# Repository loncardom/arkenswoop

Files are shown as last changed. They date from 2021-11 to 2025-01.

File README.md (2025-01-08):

# Arkenswoop

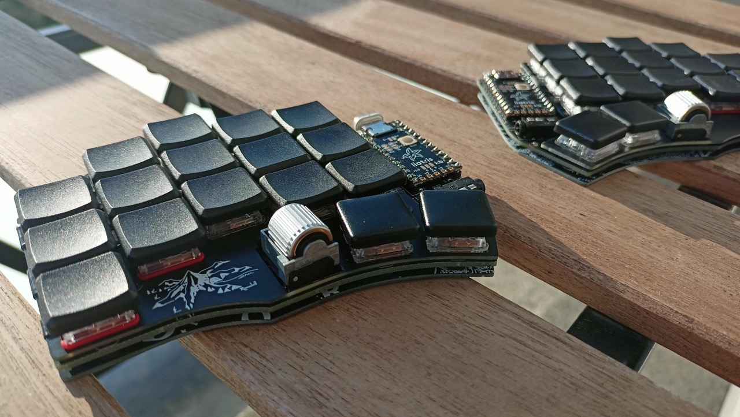
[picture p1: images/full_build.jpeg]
Fully assembled Arkenswoop


A WIP fork of [jimmerricks's Swoop](https://github.com/jimmerricks/swoop), which is a fork of [David Barr's Sweep](https://github.com/davidphilipbarr/Sweep), which is itself based on the fabulous [Ferris by Pierre Chevalier](https://github.com/pierrechevalier83/ferris).

| Front | Back |
| :---: | :---: |
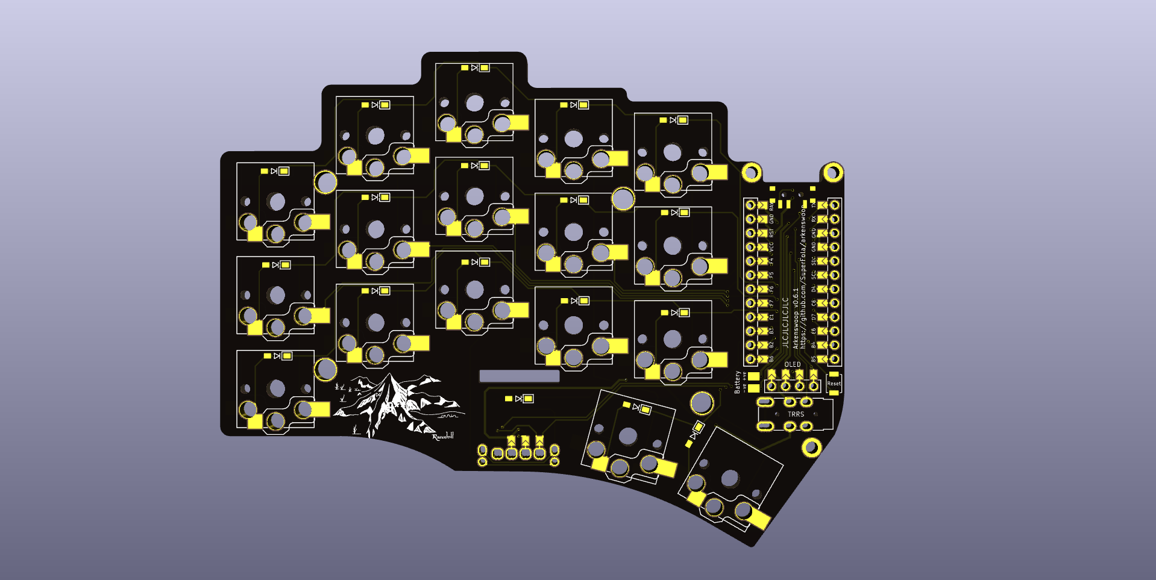
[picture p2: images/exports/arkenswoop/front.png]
front
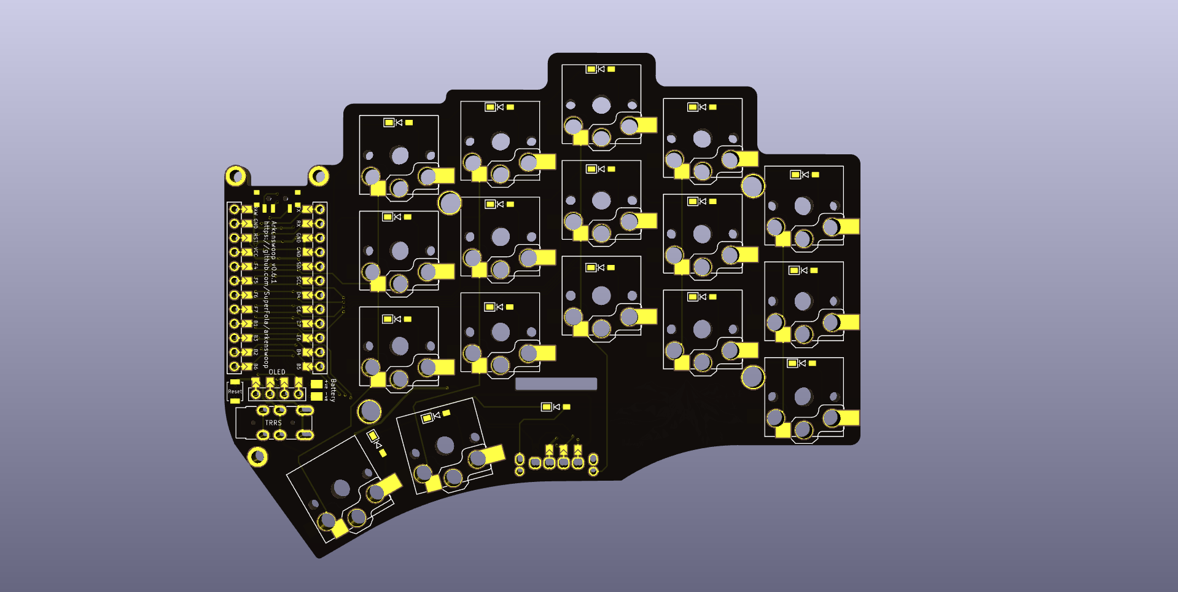
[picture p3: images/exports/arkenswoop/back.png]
back
|  |  |

### Features

⭕ Low profile Kailh Choc switches  
⭕ Hotswap  
⭕ Dual side-scrolling encoder  
⭕ Oled screens  
⭕ Power switch for battery management  
⭕ Bluetooth support w/ nice!nano  
⭕ Plate style case with mcu cover

### Components list

To build and use an Arkenswoop you will need:

* 1× PCB Kit (1.6mm thickness when ordering)
* 1× back plate kit (optional, 1.2mm thickness when ordering)
* 2× promicro compatible boards or 2 nice!nanos.
* 34× Kailh Choc v1 switches
* 34× Kailh Choc hotswap sockets (PG1350)
* 34× keycaps
* 34× SMD diodes (1N4148W, SOD-123)
* 2× side-scrolling encoders EVQWGD001
* 2× OLED LCD Display 128x32 SSD1306 (optional)
* 2× MCU cover (optional, 1mm thickness when ordering)
* 2× reset switches (optional; B3U-1000P(M))
* Some little rubber feet/bumpers (minimum of 4 on each side)
* 2× power switches (wireless only; MSK 12C02)
* 2× lipo batteries (wireless only; 301230 or 301228)
* 1× TRRS (not TRS!) cable (wired only)
* 2× TRRS Jack [PJ-320A] (wired only)
* 1× USB Cable (depends on your micro-controller choice)

## Images

<details>
    <summary>Assembled Arkenswoop 0.6.0</summary>
    
</details>
<details>
    <summary>Back of assembled Arkenswoop 0.6.0</summary>
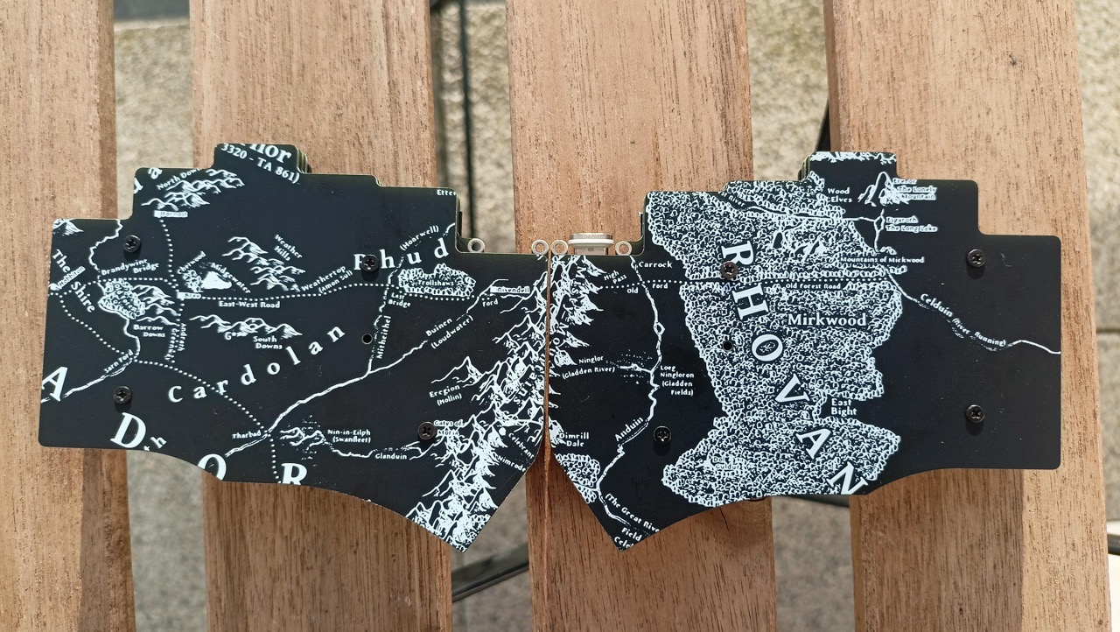
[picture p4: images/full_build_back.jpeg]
    
</details>

# Altenswoop

An Arkenswoop inspired keyboard with a twist: the Z and / keys are moved to the side.

| Front | Back |
| :---: | :---: |
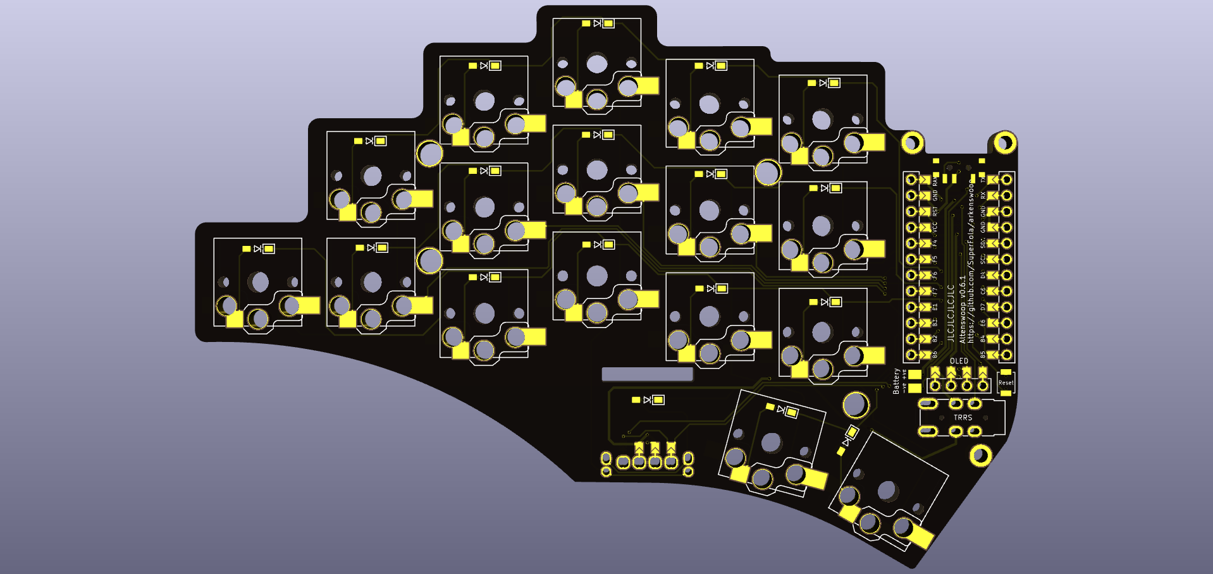
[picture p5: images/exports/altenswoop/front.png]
front
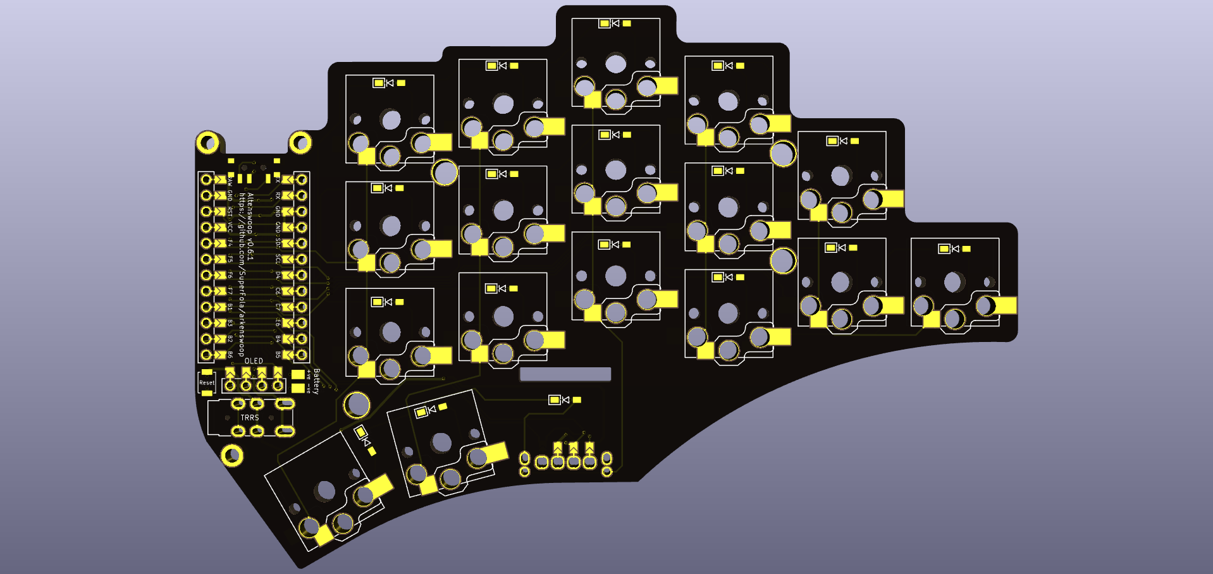
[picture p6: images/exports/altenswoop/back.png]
back
|  |  |

### Features

⭕ Low profile Kailh Choc switches  
⭕ Hotswap  
⭕ Dual side-scrolling encoder  
⭕ Oled screens  
⭕ Power switch for battery management  
⭕ Bluetooth support w/ nice!nano  
⭕ Plate style case with mcu cover

### Components list

To build and use an Altenswoop you will need:

* 1× PCB Kit (1.6mm thickness when ordering)
* 1× back plate kit (optional, 1.2mm thickness when ordering)
* 2× promicro compatible boards or 2 nice!nanos.
* 34× Kailh Choc v1 switches
* 34× Kailh Choc hotswap sockets (PG1350)
* 34× keycaps
* 34× SMD diodes (1N4148W, SOD-123)
* 2× side-scrolling encoders EVQWGD001
* 2× OLED LCD Display 128x32 SSD1306 (optional)
* 2× MCU cover (optional, 1mm thickness when ordering)
* 2× reset switches (optional; B3U-1000P(M))
* Some little rubber feet/bumpers (minimum of 4 on each side)
* 2× power switches (wireless only; MSK 12C02)
* 2× lipo batteries (wireless only; 301230 or 301228)
* 1× TRRS (not TRS!) cable (wired only)
* 2× TRRS Jack [PJ-320A] (wired only)
* 1× USB Cable (depends on your micro-controller choice)

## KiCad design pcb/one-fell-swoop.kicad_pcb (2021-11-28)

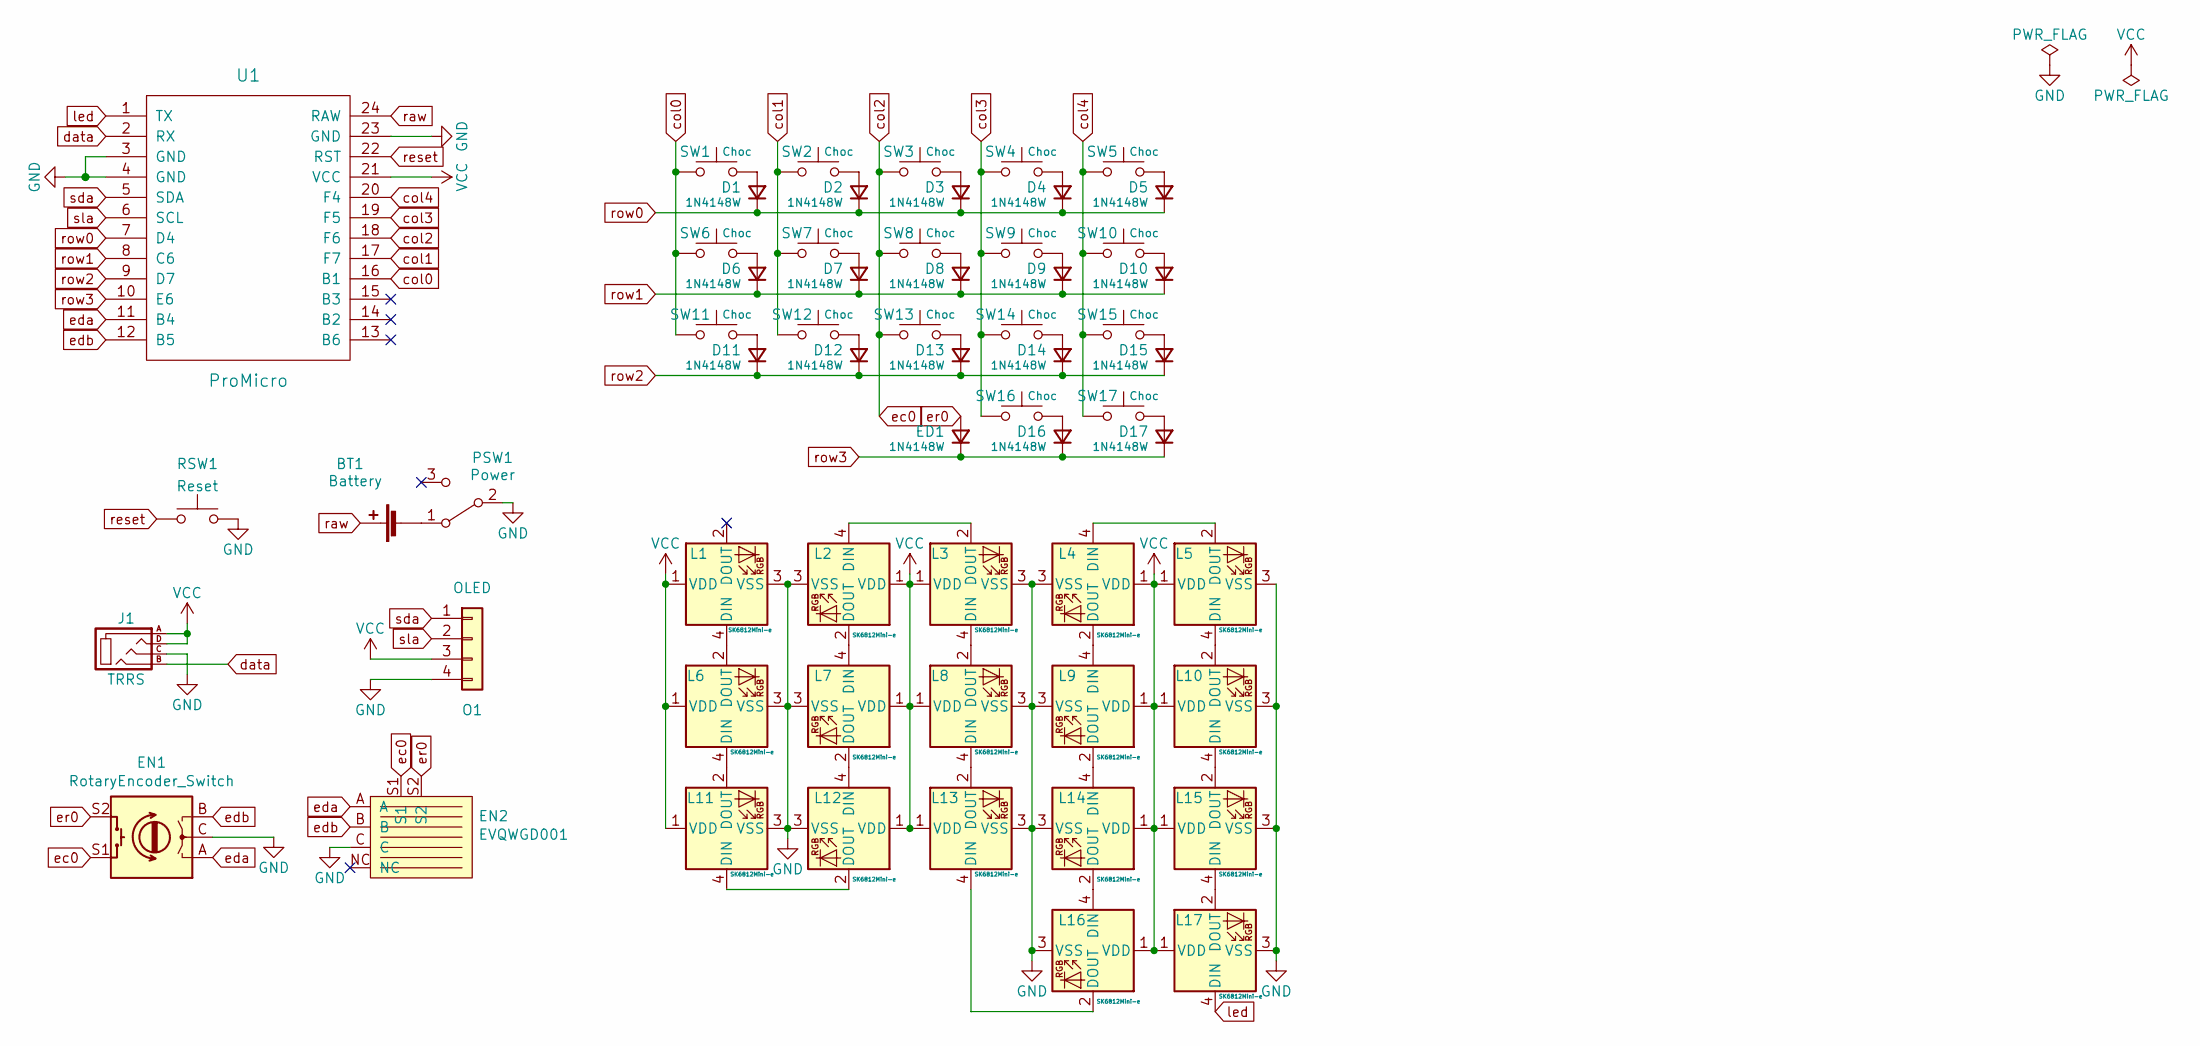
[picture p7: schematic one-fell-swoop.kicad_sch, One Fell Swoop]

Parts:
BT1: Battery; Battery_pads
D1, D2, D3, D4, D5, D6, D7, D8, D9, D10, D11, D12, D13, D14, D15, D16, D17: 1N4148W; D3_SMD
ED1: 1N4148W; D3_SMD
EN1: RotaryEncoder_Switch; RotaryEncoder
EN2: EVQWGD001; RollerEncoder
J1: TRRS; TRRS-3pin
L1, L2, L3, L4, L5, L6, L7, L8, L9, L10, L11, L12, L13, L14, L15, L16, L17: SK6812Mini-e; SK6812_Mini_E; JLCPCB BOM 0
O1: OLED; OLED_jumpers
PSW1: Power
RSW1: Reset
SW1, SW2, SW3, SW4, SW5, SW6, SW7, SW8, SW9, SW10, SW11, SW12, SW13, SW14, SW15, SW16, SW17: Choc
U1: ProMicro; ProMicro_jumpers

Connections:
GND: EN1.C, EN2.C, J1.C, L1.3 (VSS), L2.3 (VSS), L3.3 (VSS), L4.3 (VSS), L5.3 (VSS), L6.3 (VSS), L7.3 (VSS), L8.3 (VSS), L9.3 (VSS), L10.3 (VSS), L11.3 (VSS), L12.3 (VSS), L13.3 (VSS), L14.3 (VSS), L15.3 (VSS), L16.3 (VSS), L17.3 (VSS), O1.4, PSW1.2 (B), RSW1.2, U1.3 (GND), U1.4 (GND), U1.23 (GND)
unnamed: BT1.2 (-), PSW1.1 (A)
unnamed: D1.2 (A), SW1.2
unnamed: D2.2 (A), SW2.2
unnamed: D3.2 (A), SW3.2
unnamed: D4.2 (A), SW4.2
unnamed: D5.2 (A), SW5.2
unnamed: D6.2 (A), SW6.2
unnamed: D7.2 (A), SW7.2
unnamed: D8.2 (A), SW8.2
unnamed: D9.2 (A), SW9.2
unnamed: D10.2 (A), SW10.2
unnamed: D11.2 (A), SW11.2
unnamed: D12.2 (A), SW12.2
unnamed: D13.2 (A), SW13.2
unnamed: D14.2 (A), SW14.2
unnamed: D15.2 (A), SW15.2
unnamed: D16.2 (A), SW16.2
unnamed: D17.2 (A), SW17.2
unnamed: L1.4 (DIN), L6.2 (DOUT)
unnamed: L2.2 (DOUT), L7.4 (DIN)
unnamed: L2.4 (DIN), L3.2 (DOUT)
unnamed: L3.4 (DIN), L8.2 (DOUT)
unnamed: L4.2 (DOUT), L9.4 (DIN)
unnamed: L4.4 (DIN), L5.2 (DOUT)
unnamed: L5.4 (DIN), L10.2 (DOUT)
unnamed: L10.4 (DIN), L15.2 (DOUT)
unnamed: L6.4 (DIN), L11.2 (DOUT)
unnamed: L11.4 (DIN), L12.2 (DOUT)
unnamed: L7.2 (DOUT), L12.4 (DIN)
unnamed: L8.4 (DIN), L13.2 (DOUT)
unnamed: L13.4 (DIN), L16.2 (DOUT)
unnamed: L14.2 (DOUT), L16.4 (DIN)
unnamed: L9.2 (DOUT), L14.4 (DIN)
unnamed: L15.4 (DIN), L17.2 (DOUT)
VCC: J1.A, J1.D, L1.1 (VDD), L2.1 (VDD), L3.1 (VDD), L4.1 (VDD), L5.1 (VDD), L6.1 (VDD), L7.1 (VDD), L8.1 (VDD), L9.1 (VDD), L10.1 (VDD), L11.1 (VDD), L12.1 (VDD), L13.1 (VDD), L14.1 (VDD), L15.1 (VDD), L16.1 (VDD), L17.1 (VDD), O1.3, U1.21 (VCC)
col0: SW1.1, SW6.1, SW11.1, U1.16 (B1)
col1: SW2.1, SW7.1, SW12.1, U1.17 (F7)
col2: EN1.S1, EN2.S1, SW3.1, SW8.1, SW13.1, U1.18 (F6)
col3: SW4.1, SW9.1, SW14.1, SW16.1, U1.19 (F5)
col4: SW5.1, SW10.1, SW15.1, SW17.1, U1.20 (F4)
data: J1.B, U1.2 (RX)
eda: EN1.A, EN2.A, U1.11 (B4)
edb: EN1.B, EN2.B, U1.12 (B5)
er0: ED1.2 (A), EN1.S2, EN2.S2
led: L17.4 (DIN), U1.1 (TX)
raw: BT1.1 (+), U1.24 (RAW)
reset: RSW1.1, U1.22 (RST)
row0: D1.1 (K), D2.1 (K), D3.1 (K), D4.1 (K), D5.1 (K), U1.7 (D4)
row1: D6.1 (K), D7.1 (K), D8.1 (K), D9.1 (K), D10.1 (K), U1.8 (C6)
row2: D11.1 (K), D12.1 (K), D13.1 (K), D14.1 (K), D15.1 (K), U1.9 (D7)
row3: D16.1 (K), D17.1 (K), ED1.1 (K), U1.10 (E6)
sda: O1.1, U1.5 (SDA)
sla: O1.2, U1.6 (SCL)

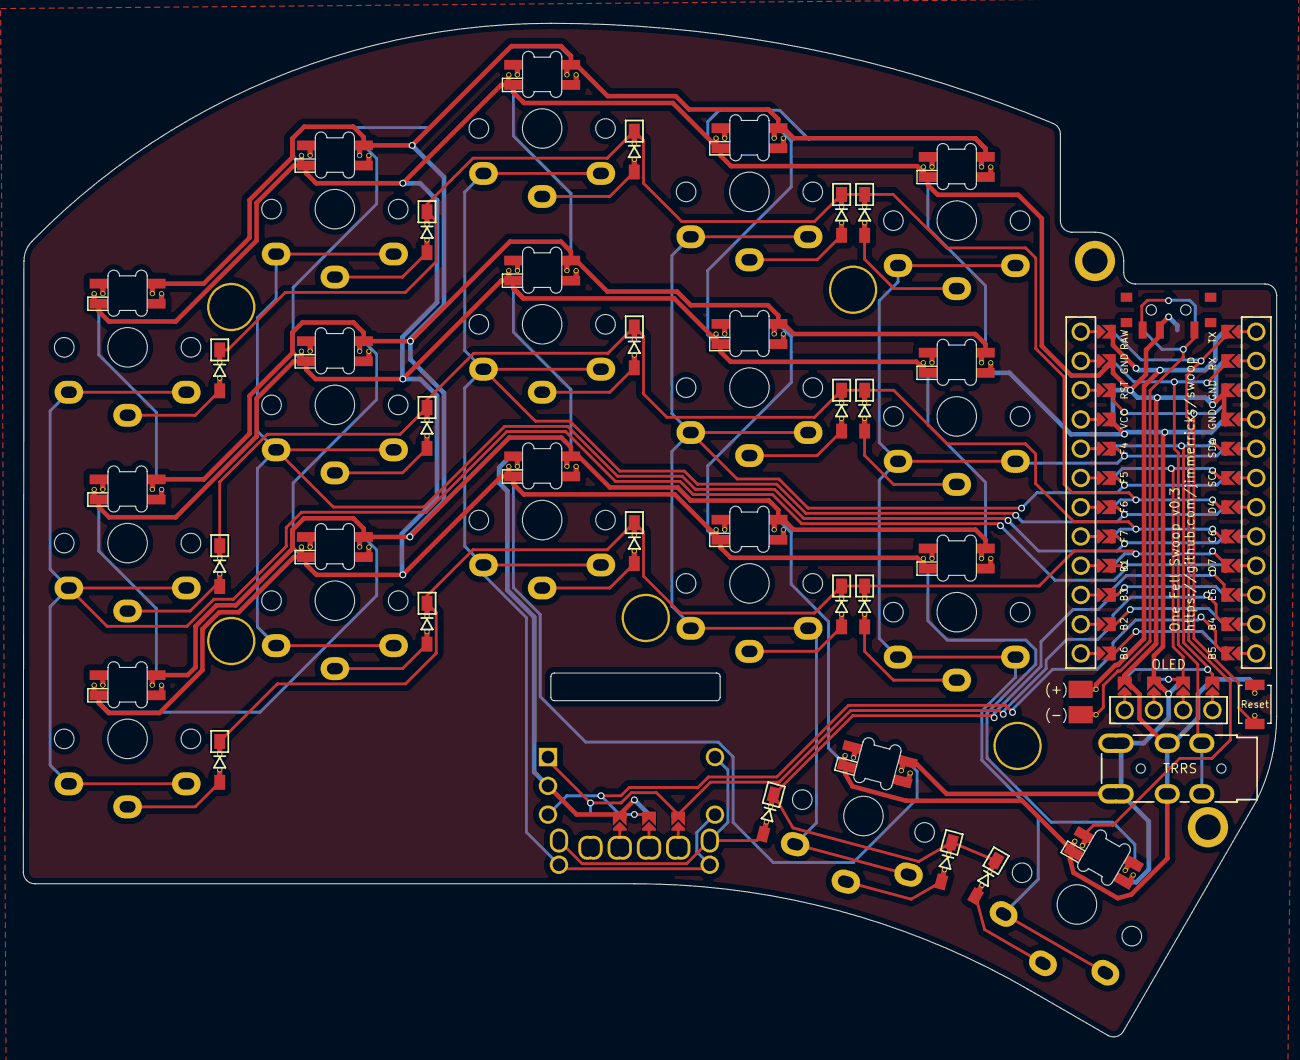
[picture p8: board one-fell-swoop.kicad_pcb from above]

Board: 2 copper layers, 108.8 x 88.0 mm, 67 parts (0 on the bottom side), 54 nets.

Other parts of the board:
H1, H2, H3, H4, H4#2: M2 Hole; M2_hole_4.2mm
Ref**: Val**; M2_hole_3.5mm_2mm
Ref**#2: Val**; M2_hole_3.5mm_2mm

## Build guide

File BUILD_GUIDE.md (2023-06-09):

# Arkenswoop build guide

## Non hotswap version

**Important**: the soldered MCU jumper pads should be on the same side as the switches, encoder and MCU ; the diodes should be on the back on the PCB.

1. put your PCBs in front of you, one on each side
2. solder the jumper pads on the top: this will be the side where the keys are
    * be careful to solder the jumper pads for the **encoder** on the back!
3. (optional) put the MCU sockets and tape them so that they won't move
    *  if you don't have sockets you can skip this step ; however note that you will have to permanently solder your MCU
4. put the TRRS jack and tape it
5. flip over the PCBs and solder the TRRS jack and sockets (optional)
    * to make it easier, first solder the corners of the sockets, and ensure everything is aligned correctly before going any further
6. for each diode footprint, solder one pad
7. take a diode, which the mark being on the same side as the silk on the PCB, put it over a pad you have tinned, and heat the pad ; the diode should stay in place nicely
8. solder the other leg of the diode
9. repeat 7 -> 8 for every other diode
    * if you have trouble putting diodes near each other, try holding them by their legs which twizzers
10. flip your board over, and start placing your switches ; be careful not to bend any pin
    * the switches should stay in place, without any tape
11. solder your switches: your iron should be in contact with both the pad and the pin, then put your solder on the pad and it will melt easily
12. put the encoder and solder its pins in the same fashion

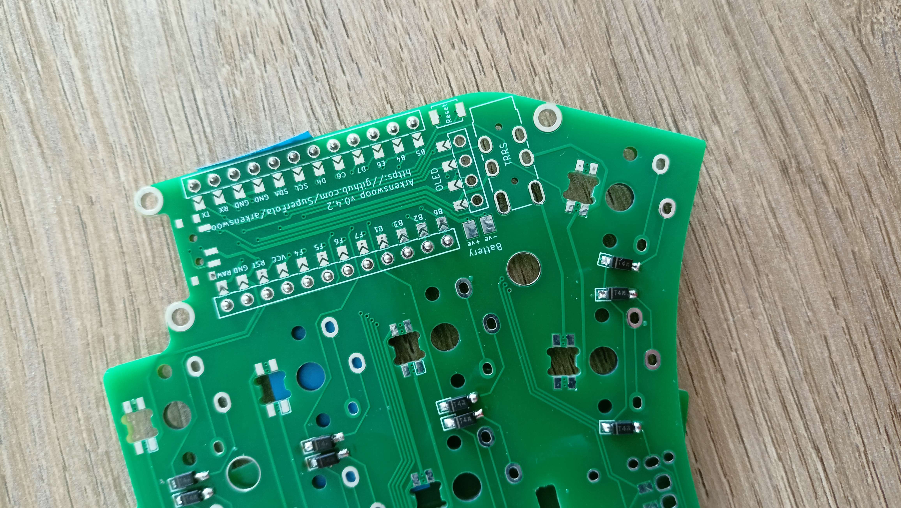
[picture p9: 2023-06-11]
images/build/05_mcu_sockets_underneath_pcb.jpg

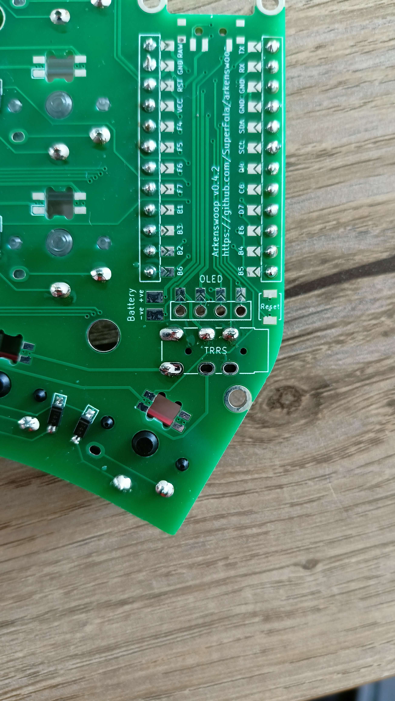
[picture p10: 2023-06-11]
images/build/12_soldered_trrs_jack.jpg

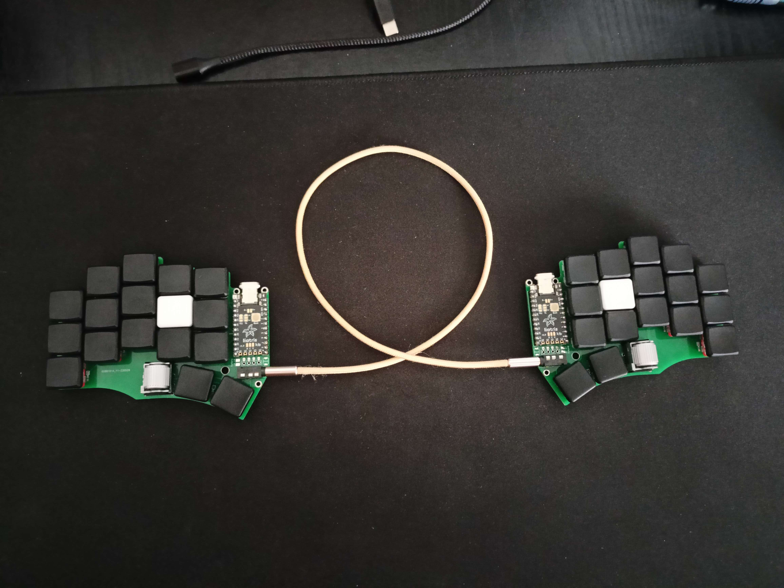
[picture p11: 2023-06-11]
images/build/full_build.jpg

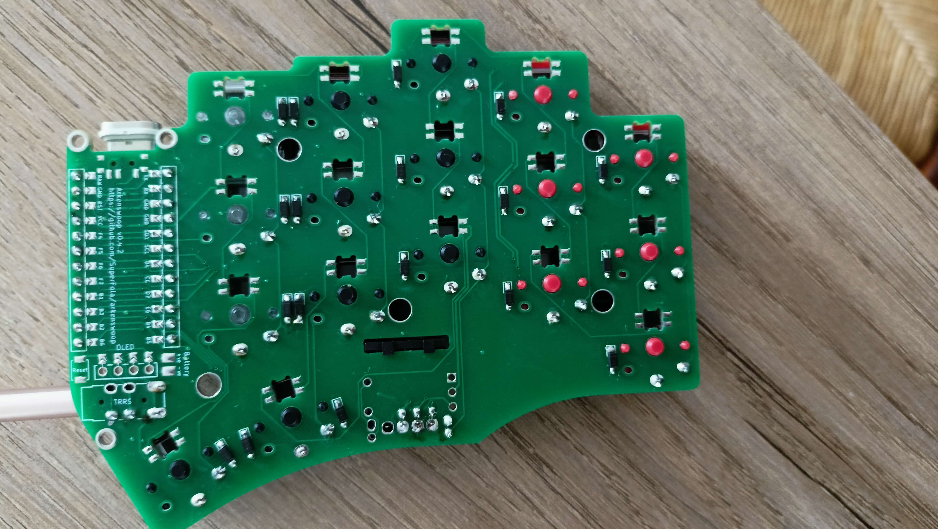
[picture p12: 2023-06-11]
images/build/13_soldered_encoder_and_jumper_pads.jpg

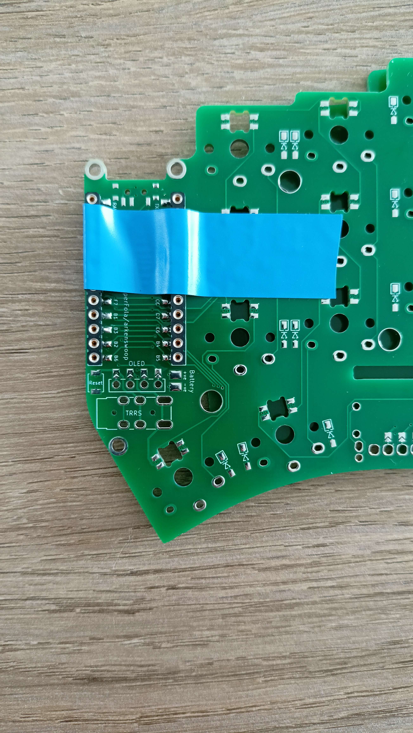
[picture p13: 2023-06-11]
images/build/04_soldering_mcu_sockets.jpg

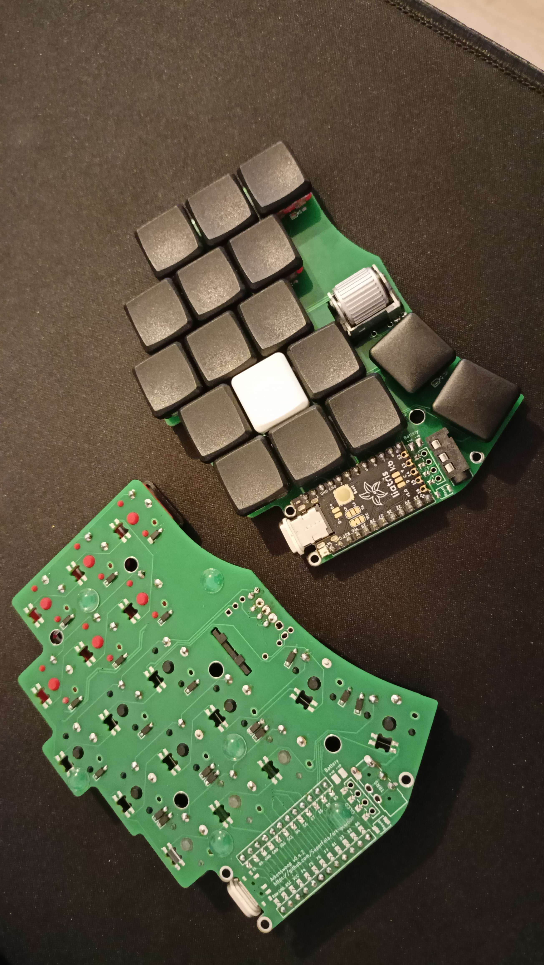
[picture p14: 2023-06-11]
images/build/right_half_and_left_half_flipped.jpg

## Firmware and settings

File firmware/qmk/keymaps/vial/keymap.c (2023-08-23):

/* Copyright 2023 Alexandre Plateau <lexplt.dev@gmail.com>
 *
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
 * You should have received a copy of the GNU General Public License
 * along with this program.  If not, see <http://www.gnu.org/licenses/>.
 */
#include QMK_KEYBOARD_H

#if defined(ENCODER_MAP_ENABLE)
const uint16_t PROGMEM encoder_map[][NUM_ENCODERS][2] = {
    [0] =   { ENCODER_CCW_CW(KC_MS_WH_UP, KC_MS_WH_DOWN), ENCODER_CCW_CW(KC_VOLD, KC_VOLU)  },
    [1] =   { ENCODER_CCW_CW(KC_MS_WH_UP, KC_MS_WH_DOWN), ENCODER_CCW_CW(KC_VOLD, KC_VOLU)  },
    [2] =   { ENCODER_CCW_CW(RGB_VAD, RGB_VAI),           ENCODER_CCW_CW(RGB_SPD, RGB_SPI)  },
    [3] =   { ENCODER_CCW_CW(RGB_RMOD, RGB_MOD),          ENCODER_CCW_CW(KC_F14, KC_F15) },
    [4] =   { ENCODER_CCW_CW(RGB_RMOD, RGB_MOD),          ENCODER_CCW_CW(KC_RIGHT, KC_LEFT) },
    [5] =   { ENCODER_CCW_CW(RGB_RMOD, RGB_MOD),          ENCODER_CCW_CW(KC_RIGHT, KC_LEFT) },
    //                  Encoder 1                                     Encoder 2
};
#endif

const uint16_t PROGMEM keymaps[][MATRIX_ROWS][MATRIX_COLS] = {
  [0] = LAYOUT_split_3x5_3(
    KC_Q,   KC_W,   KC_E,  KC_R,   KC_T,            KC_Y,   KC_U,   KC_I,   KC_O,   KC_P,
    KC_A,   KC_S,   KC_D,  KC_F,   KC_G,            KC_H,   KC_J,   KC_K,   KC_L,   KC_SCLN,
    KC_Z,   KC_X,   KC_C,  KC_V,   KC_B,            KC_N,   KC_M,   KC_COMM, KC_DOT, KC_SLASH,
                 QK_BOOT, KC_ESC, KC_SPACE,      KC_BSPC,   KC_ENTER, KC_NO
  ),

  [1] = LAYOUT_split_3x5_3(
    KC_NO,   KC_NO,   KC_NO,   KC_NO,   KC_NO,       KC_NO,   KC_NO,   KC_NO,   KC_NO,   KC_NO,
    KC_NO,   KC_NO,   KC_NO,   KC_NO,   KC_NO,       KC_NO,   KC_NO,   KC_NO,   KC_NO,   KC_NO,
    KC_NO,   KC_NO,   KC_NO,   KC_NO,   KC_NO,       KC_NO,   KC_NO,   KC_NO,   KC_NO,   KC_NO,
                      KC_NO,   KC_TRNS, KC_TRNS,     KC_TRNS, KC_TRNS, KC_NO
  ),

  [2] = LAYOUT_split_3x5_3(
    KC_NO,   KC_NO,   KC_NO,   KC_NO,   KC_NO,       KC_NO,   KC_NO,   KC_NO,   KC_NO,   KC_NO,
    KC_NO,   KC_NO,   KC_NO,   KC_NO,   KC_NO,       KC_NO,   KC_NO,   KC_NO,   KC_NO,   KC_NO,
    KC_NO,   KC_NO,   KC_NO,   KC_NO,   KC_NO,       KC_NO,   KC_NO,   KC_NO,   KC_NO,   KC_NO,
                      KC_NO,   KC_TRNS, KC_TRNS,     KC_TRNS, KC_TRNS, KC_NO
  ),

  [3] = LAYOUT_split_3x5_3(
    KC_NO,   KC_NO,   KC_NO,   KC_NO,   KC_NO,       KC_NO,   KC_NO,   KC_NO,   KC_NO,   KC_NO,
    KC_NO,   KC_NO,   KC_NO,   KC_NO,   KC_NO,       KC_NO,   KC_NO,   KC_NO,   KC_NO,   KC_NO,
    KC_NO,   KC_NO,   KC_NO,   KC_NO,   KC_NO,       KC_NO,   KC_NO,   KC_NO,   KC_NO,   KC_NO,
                      KC_NO,   KC_TRNS, KC_TRNS,     KC_TRNS, KC_TRNS, KC_NO
  ),

  [4] = LAYOUT_split_3x5_3(
    KC_NO,   KC_NO,   KC_NO,   KC_NO,   KC_NO,       KC_NO,   KC_NO,   KC_NO,   KC_NO,   KC_NO,
    KC_NO,   KC_NO,   KC_NO,   KC_NO,   KC_NO,       KC_NO,   KC_NO,   KC_NO,   KC_NO,   KC_NO,
    KC_NO,   KC_NO,   KC_NO,   KC_NO,   KC_NO,       KC_NO,   KC_NO,   KC_NO,   KC_NO,   KC_NO,
                      KC_NO,   KC_TRNS, KC_TRNS,     KC_TRNS, KC_TRNS, KC_NO
  ),

  [5] = LAYOUT_split_3x5_3(
    KC_NO,   KC_NO,   KC_NO,   KC_NO,   KC_NO,       KC_NO,   KC_NO,   KC_NO,   KC_NO,   KC_NO,
    KC_NO,   KC_NO,   KC_NO,   KC_NO,   KC_NO,       KC_NO,   KC_NO,   KC_NO,   KC_NO,   KC_NO,
    KC_NO,   KC_NO,   KC_NO,   KC_NO,   KC_NO,       KC_NO,   KC_NO,   KC_NO,   KC_NO,   KC_NO,
                      KC_NO,   KC_TRNS, KC_TRNS,     KC_TRNS, KC_TRNS, KC_NO
  ),
};

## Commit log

2021-10-11 First commit of One Fell Swoop keyboard.
    [ferris-sweep-compact.dsn, ferris-sweep-compact.kicad_pcb, ferris-sweep-compact.sch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]
2021-11-14 Added files for the second version of the Swoop.
    [one-fell-swoop.kicad_pcb, one-fell-swoop.kicad_sch]
2021-11-28 v0.3: fixed route fail, changed shape, added cover
    [one-fell-swoop.kicad_pcb, one-fell-swoop.kicad_sch]
2021-11-28 Added plates for a v0.3 case.
    [one-fell-swoop-base-plate.kicad_pcb, one-fell-swoop-cover.kicad_pcb, one-fell-swoop-mid-plate.kicad_pcb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]
2021-12-11 Footprints for the Swoop choc and mx
2021-12-11 Reorganised the Choc
    [one-fell-swoop-base-plate.kicad_pcb, one-fell-swoop-cover.dxf, one-fell-swoop-cover.kicad_pcb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]
2021-12-11 Added the Swoop MX
    [swoop-mx-base-plate-puck.dxf, swoop-mx-base-plate-puck.kicad_pcb, swoop-mx-base-plate-puck.step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]
2022-02-02 Repository reorganised.
    [swoop-choc.kicad_pcb, swoop-choc.kicad_sch, swoop-choc.sch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]
2022-02-02 Plates and gerbers removed.
    [one-fell-swoop-base-plate.kicad_pcb, one-fell-swoop-cover.dxf, one-fell-swoop-cover.kicad_pcb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]
2022-02-02 Files renamed and corrections made.
    [howarya.kicad_pcb, howarya.kicad_sch, howarya.sch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]
2022-02-03 Name change
    [howarya.kicad_pcb, howarya.kicad_sch]
2022-02-03 Fixed the cover
    [swoop.kicad_pcb, swoop.kicad_sch]
2022-08-05 Removed LED strip and normalised LED order.
    [howarya.kicad_pcb, howarya.kicad_sch]
2023-05-28 Adding the arkenswoop as a remix of the Swoop 0.4.2
    [arkenswoop-B_Cu.gbl, arkenswoop-B_Mask.gbs, arkenswoop-B_Paste.gbp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]
2023-05-28 Clean up, see original files on the parent repo
    [howarya.kicad_pcb, howarya.kicad_sch, howarya.sch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]
2023-06-09 wip: vial integrations and liatris leds
2023-06-09 small update to readme and plates
    [plates-B_Cu.gbl, plates-B_Mask.gbs, plates-B_Paste.gbp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]
2023-06-12 moving the encoder about 0.3mm down ; this should give enough clearance to the nearest key and its keycap
    [arkenswoop.kicad_pcb]
2023-06-12 removed leds footprint
    [arkenswoop.kicad_pcb]
2023-06-12 removed leds from schematic
    [arkenswoop.kicad_sch]
2023-06-12 added silkscreens and exported 3D renders of the modified pcb and plates
2023-06-12 removed leds from the readme
2023-06-12 changed the holes for 2.2mm on the back plates
    [plates-B_Cu.gbl, plates-B_Mask.gbs, plates-B_Paste.gbp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]
2023-06-12 customized pcb to have the jlcpcb order number under the mcu
    [arkenswoop-B_Cu.gbl, arkenswoop-B_Mask.gbs, arkenswoop-B_Paste.gbp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]
2023-06-25 adding hotswap arkenswoop
    [arkenswoop-B_Cu.gbl, arkenswoop-B_Mask.gbs, arkenswoop-B_Paste.gbp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]
2023-06-25 redoing the plates because of the larger size of the hotswap version
    [plates-B_Cu.gbl, plates-B_Mask.gbs, plates-B_Paste.gbp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]
2023-06-25 removing old soldered version
    [arkenswoop-B_Cu.gbl, arkenswoop-B_Mask.gbs, arkenswoop-B_Paste.gbp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]
2023-06-25 adding images of the back plates
2023-06-25 added silk on pcb
    [arkenswoop.kicad_pcb]
2023-06-25 added renders of pcbs
2023-06-25 adding gerbers
    [arkenswoop-B_Cu.gbl, arkenswoop-B_Mask.gbs, arkenswoop-B_Paste.gbp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]
2023-06-25 added switch plate
    [switch-plates-B_Cu.gbl, switch-plates-B_Mask.gbs, switch-plates-B_Paste.gbp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]
2023-07-09 moved the standard Arkenswoop to pcbs/3x5_2
    [arkenswoop-B_Cu.gbl, arkenswoop-B_Mask.gbs, arkenswoop-B_Paste.gbp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]
2023-07-09 adding the altenswoop, an arkenswoop with a north-west pinky cluster
    [altenswoop.kicad_pcb, altenswoop.kicad_sch]
2023-07-28 redoing the switch plates cutouts and adding a proper kicad library
    [arkenswoop-B_Cu.gbl, arkenswoop-B_Mask.gbs, arkenswoop-B_Paste.gbp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]
2023-07-28 updating kailh reversible footprint to add switch outline
    [arkenswoop.kicad_pcb]
2023-07-28 adding the net classes to the sockets which got removed when updating footprints
    [arkenswoop-B_Cu.gbl, arkenswoop-B_Mask.gbs, arkenswoop-B_Paste.gbp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]
2023-08-10 adding the altenswoop
    [altenswoop.kicad_pcb, backplate.kicad_pcb, backplate.kicad_sch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]
2023-08-10 fixing traces thanks to DRC on the altenswoop
    [altenswoop.kicad_pcb]
2023-08-23 adding mcu cover
    [plate-cover.kicad_pcb]
2023-08-23 removing gerbers/ folders, only keeping gerbers.zip
    [arkenswoop-B_Cu.gbl, arkenswoop-B_Mask.gbs, arkenswoop-B_Paste.gbp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]
2024-12-29 Update components list to add the forgotten diodes

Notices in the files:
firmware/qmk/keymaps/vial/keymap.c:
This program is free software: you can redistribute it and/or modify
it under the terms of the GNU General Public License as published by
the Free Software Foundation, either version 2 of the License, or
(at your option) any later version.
